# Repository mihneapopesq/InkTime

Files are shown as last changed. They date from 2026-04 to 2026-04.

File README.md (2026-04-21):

# InkTime

## Block Diagram
The system architecture centers on the nRF52840 SoC for wireless connectivity, with power stabilized at 3.3V via an RT6160 buck-boost regulator. It integrates a LiPo battery with USB-C charging alongside an e-paper display, IMU, fuel gauge, and haptic feedback.

Block_Diagram

## Bill of Materials (BOM)

|Component|JLC Part #|Package|Description|Datasheet|
| :--- | :--- | :--- | :--- | :--- |
|SJ1|N/A|Solder Jumper (Copper feature - leave open)|SMD solder JUMPER|N/A|
|R2, R3, R4|[C3920633](https://www.lcsc.com/product-detail/C3920633.html)|0201|7.68k 0201 Thin Film Surface Mount Fixed Resistor +/-0.5% 0.031W CPF0201D7K68C1|[datasheet](https://wmsc.lcsc.com/wmsc/upload/file/pdf/v2/lcsc/2404081048_TE-Connectivity-CPF0201B511RE1_C3920633.pdf)|
|C23, C27, C34, C42|[C21012218](https://www.lcsc.com/product-detail/C21012218.html)|-|Check availability|[datasheet](https://jlc-prod-smt.oss-eu-central-1.aliyuncs.com/smtDataManualFile/8603520985945550848-C21012218.pdf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)|
|EPD_C5|[C9900156064](https://www.lcsc.com/product-detail/C9900156064.html)|201|Generic chip capacitor|[datasheet](https://ds.yuden.co.jp/TYCOMPAS/or/download?pn=MLAST063SCG681JFNA01&fileType=CA)|
|R1_EP_DR|[C3920633](https://www.lcsc.com/product-detail/C3920633.html)|0201|7.68k 0201 Thin Film Surface Mount Fixed Resistor +/-0.5% 0.031W CPF0201D7K68C1|[datasheet](https://wmsc.lcsc.com/wmsc/upload/file/pdf/v2/lcsc/2404081048_TE-Connectivity-CPF0201B511RE1_C3920633.pdf)|
|C15|[C9900156064](https://www.lcsc.com/product-detail/C9900156064.html)|201|Generic chip capacitor|[datasheet](https://ds.yuden.co.jp/TYCOMPAS/or/download?pn=MLAST063SCG681JFNA01&fileType=CA)|
|C5, C7, C8, C12, C19|[C9900156064](https://www.lcsc.com/product-detail/C9900156064.html)|201|Generic chip capacitor|[datasheet](https://ds.yuden.co.jp/TYCOMPAS/or/download?pn=MLAST063SCG681JFNA01&fileType=CA)|
|C11|[C9900156064](https://www.lcsc.com/product-detail/C9900156064.html)|201|Generic chip capacitor|[datasheet](https://ds.yuden.co.jp/TYCOMPAS/or/download?pn=MLAST063SCG681JFNA01&fileType=CA)|
|R2_EP_DR, R9, R_PWR_EPD|[C3920633](https://www.lcsc.com/product-detail/C3920633.html)|0201|7.68k 0201 Thin Film Surface Mount Fixed Resistor +/-0.5% 0.031W CPF0201D7K68C1|[datasheet](https://wmsc.lcsc.com/wmsc/upload/file/pdf/v2/lcsc/2404081048_TE-Connectivity-CPF0201B511RE1_C3920633.pdf)|
|R5, R7, R8|[C3920633](https://www.lcsc.com/product-detail/C3920633.html)|0201|7.68k 0201 Thin Film Surface Mount Fixed Resistor +/-0.5% 0.031W CPF0201D7K68C1|[datasheet](https://wmsc.lcsc.com/wmsc/upload/file/pdf/v2/lcsc/2404081048_TE-Connectivity-CPF0201B511RE1_C3920633.pdf)|
|C1-EP-DR|[C9900156064](https://www.lcsc.com/product-detail/C9900156064.html)|201|Generic chip capacitor|[datasheet](https://ds.yuden.co.jp/TYCOMPAS/or/download?pn=MLAST063SCG681JFNA01&fileType=CA)|
|C24, C39|[C9900179830](https://www.lcsc.com/product-detail/C9900179830.html)|402|0402 (1005 Metric)|N/A|
|L2|[C12669](https://www.lcsc.com/product-detail/C12669.html)|402|Generic chip inductor|[datasheet](https://www.lcsc.com/datasheet/lcsc_datasheet_2304140030_Murata-Electronics-LQG15HS27NJ02D_C12669.pdf)|
|C1, C2, C17, C18|[C9900156064](https://www.lcsc.com/product-detail/C9900156064.html)|201|Generic chip capacitor|[datasheet](https://ds.yuden.co.jp/TYCOMPAS/or/download?pn=MLAST063SCG681JFNA01&fileType=CA)|
|L3|[C12669](https://www.lcsc.com/product-detail/C12669.html)|402|Generic chip inductor|[datasheet](https://www.lcsc.com/datasheet/lcsc_datasheet_2304140030_Murata-Electronics-LQG15HS27NJ02D_C12669.pdf)|
|C3, C4|[C9900156064](https://www.lcsc.com/product-detail/C9900156064.html)|201|Generic chip capacitor|[datasheet](https://ds.yuden.co.jp/TYCOMPAS/or/download?pn=MLAST063SCG681JFNA01&fileType=CA)|
|C29, C30, C31, C32, C37, C38|[C3920633](https://www.lcsc.com/product-detail/C3920633.html)|0201|7.68k 0201 Thin Film Surface Mount Fixed Resistor +/-0.5% 0.031W CPF0201D7K68C1|[datasheet](https://wmsc.lcsc.com/wmsc/upload/file/pdf/v2/lcsc/2404081048_TE-Connectivity-CPF0201B511RE1_C3920633.pdf)|
|EPD_C1, EPD_C2, EPD_C6, EPD_C7, EPD_C8, EPD_C9, EPD_C10, EPD_C11, EPD_C12|[C9900156064](https://www.lcsc.com/product-detail/C9900156064.html)|201|Generic chip capacitor|[datasheet](https://ds.yuden.co.jp/TYCOMPAS/or/download?pn=MLAST063SCG681JFNA01&fileType=CA)|
|R_TYPE_SEL|[C3920633](https://www.lcsc.com/product-detail/C3920633.html)|0201|7.68k 0201 Thin Film Surface Mount Fixed Resistor +/-0.5% 0.031W CPF0201D7K68C1|[datasheet](https://wmsc.lcsc.com/wmsc/upload/file/pdf/v2/lcsc/2404081048_TE-Connectivity-CPF0201B511RE1_C3920633.pdf)|
|SW_DN, SW_ENT, SW_UP|[C569760](https://www.lcsc.com/product-detail/C569760.html)|SMD,3.9x2.9mm|-40℃~+85℃ 1.6N 1.6mm 15V 2.9mm 20mA 3.9mm 500,000 Cycles IP67 J-Lead Rectangular Button SPST Surface Mount,Vertical White With Bracket SMD,3.9x2.9mm Tactile Switches ROHS|[datasheet](https://wmsc.lcsc.com/wmsc/upload/file/pdf/v2/lcsc/2301111010_PANASONIC-EVPAKE31A_C569760.pdf)|
|Q1|[C2564](https://www.lcsc.com/product-detail/C2564.html)|TO-220AB|-55℃~+175℃ 1 P-Channel 180nC@10V 200W 20mΩ@10V 3.4nF 4V 55V 640pF 74A P-Channel TO-220AB MOSFETs ROHS|[datasheet](https://www.lcsc.com/datasheet/lcsc_datasheet_1809041724_Infineon-Technologies-IRF4905PBF_C2564.pdf)|
|C25, C33|[C9900179830](https://www.lcsc.com/product-detail/C9900179830.html)|402|0402 (1005 Metric)|N/A|
|ANT1|[C2917717](https://www.lcsc.com/product-detail/C2917717.html)|1206|-45℃~+125℃ 0.5dBi 1.3mm 1.6mm 100MHz 2.45GHz 2W 3.2mm 50Ω Patch Antenna 1206 Antennas ROHS|[datasheet](https://www.lcsc.com/datasheet/lcsc_datasheet_2404021210_Johanson-Dielectrics-2450AT18B100E_C2917717.pdf)|
|L1|[C12669](https://www.lcsc.com/product-detail/C12669.html)|402|Generic chip inductor|[datasheet](https://www.lcsc.com/datasheet/lcsc_datasheet_2304140030_Murata-Electronics-LQG15HS27NJ02D_C12669.pdf)|
|X2|[C32346](https://www.lcsc.com/product-detail/C32346.html)|SMD3215-2P|-40℃~+85℃ 12.5pF 32.768kHz 70kΩ Crystal Oscillator ±20ppm SMD3215-2P Crystals ROHS|[datasheet](https://www.lcsc.com/datasheet/lcsc_datasheet_2404180925_Seiko-Epson-Q13FC13500004_C32346.pdf)|
|X1|[C9009](https://www.lcsc.com/product-detail/C9009.html)|SMD3225-4P|-40℃~+85℃ 12pF 32MHz Crystal Oscillator ±10ppm ±20ppm SMD3225-4P Crystals ROHS|[datasheet](https://www.lcsc.com/datasheet/lcsc_datasheet_2403291504_YXC-Crystal-Oscillators-X322532MOB4SI_C9009.pdf)|
|R17, R18|[C3920633](https://www.lcsc.com/product-detail/C3920633.html)|0201|7.68k 0201 Thin Film Surface Mount Fixed Resistor +/-0.5% 0.031W CPF0201D7K68C1|[datasheet](https://wmsc.lcsc.com/wmsc/upload/file/pdf/v2/lcsc/2404081048_TE-Connectivity-CPF0201B511RE1_C3920633.pdf)|
|C43|[C9900156064](https://www.lcsc.com/product-detail/C9900156064.html)|201|Generic chip capacitor|[datasheet](https://ds.yuden.co.jp/TYCOMPAS/or/download?pn=MLAST063SCG681JFNA01&fileType=CA)|
|C2-EP-DR|[C9900156064](https://www.lcsc.com/product-detail/C9900156064.html)|201|Generic chip capacitor|[datasheet](https://ds.yuden.co.jp/TYCOMPAS/or/download?pn=MLAST063SCG681JFNA01&fileType=CA)|
|C6, C14, C20, C21|[C9900156064](https://www.lcsc.com/product-detail/C9900156064.html)|201|Generic chip capacitor|[datasheet](https://ds.yuden.co.jp/TYCOMPAS/or/download?pn=MLAST063SCG681JFNA01&fileType=CA)|
|C16|[C9900156064](https://www.lcsc.com/product-detail/C9900156064.html)|201|Generic chip capacitor|[datasheet](https://ds.yuden.co.jp/TYCOMPAS/or/download?pn=MLAST063SCG681JFNA01&fileType=CA)|
|J1|[C122434](https://www.lcsc.com/product-detail/C122434.html)|SMD,P=0.5mm,Surface Mount，Right Angle|FFC & FPC Connectors 0.5mm FPC RA SMT Dual Contact 24Ckt|[datasheet](https://www.molex.com/content/dam/molex/molex-dot-com/products/automated/en-us/salesdrawingpdf/503/503480/5034802400_sd.pdf)|
|R1_USB, R2_USB|[C3920633](https://www.lcsc.com/product-detail/C3920633.html)|0201|7.68k 0201 Thin Film Surface Mount Fixed Resistor +/-0.5% 0.031W CPF0201D7K68C1|[datasheet](https://wmsc.lcsc.com/wmsc/upload/file/pdf/v2/lcsc/2404081048_TE-Connectivity-CPF0201B511RE1_C3920633.pdf)|
|L5|[C1329646](https://www.lcsc.com/product-detail/C1329646.html)|SMD,4.8x4.8mm|1.6A 1.6A 4.7uH 41.4mΩ AEC-Q200 ±30% SMD,4.8x4.8mm Power Inductors ROHS|[datasheet](https://wmsc.lcsc.com/wmsc/upload/file/pdf/v2/lcsc/2304140030_BOURNS-SRR4828A-4R7Y_C1329646.pdf)|
|C9|[C9900156064](https://www.lcsc.com/product-detail/C9900156064.html)|201|Generic chip capacitor|[datasheet](https://ds.yuden.co.jp/TYCOMPAS/or/download?pn=MLAST063SCG681JFNA01&fileType=CA)|
|IC3|[C189517](https://www.lcsc.com/product-detail/C189517.html)|LGA-12(2x2)|Accelerometers Triaxial low-g 12bit Acceleration Sensor|[datasheet](https://www.lcsc.com/datasheet/C189517.pdf)|
|IC1|[C3682423](https://www.lcsc.com/product-detail/C3682423.html)|DSBGA-8(1.1x1.6)|Charger IC Lithium Ion/Polymer, Lithium Iron Phosphate 8-DSBGA (1.6x1.1)|[datasheet](https://www.ti.com/cn/lit/ds/symlink/bq25180.pdf?ts=1775594237116)|
|IC2|[C81079](https://www.lcsc.com/product-detail/C81079.html)|DSBGA-9|Haptic Driver for ERM/LRA with Built-In Library and Smart Loop Architecture|[datasheet](https://www.ti.com/cn/lit/gpn/drv2605)|
|L7|[C5832368](https://www.lcsc.com/product-detail/C5832368.html)|1008|13mΩ 470nH 6.5A 7.5A ±20% 1008 Power Inductors ROHS|[datasheet](https://wmsc.lcsc.com/wmsc/upload/file/pdf/v2/lcsc/2306021632_cjiang--Changjiang-Microelectronics-Tech-FTC252012SR47MBCA_C5832368.pdf)|
|TP (Test Pads)|N/A|N/A|Test pad|N/A|
|J4|[C709357](https://www.lcsc.com/product-detail/C709357.html)|SMD|-40℃~+85℃ 1 10,000 cycles 16P 30V 3A 7.81mm Female Surface Mount, Right Angle Type-C SMD USB Connectors ROHS|[datasheet](https://www.lcsc.com/datasheet/lcsc_datasheet_2404191039_Shenzhen-Kinghelm-Elec-KH-TYPE-C-16P_C709357.pdf)|
|U2|[C2682616](https://www.lcsc.com/product-detail/C2682616.html)|DFN-8-EP(2x2)|-40℃~+85℃ 1 2.5V~4.5V 3uA I2C Lithium Battery DFN-8-EP(2x2) Battery Management ROHS|[datasheet](https://www.lcsc.com/datasheet/lcsc_datasheet_2410121738_Analog-Devices-Inc--Maxim-Integrated-MAX17048G-T10_C2682616.pdf)|
|D2, D4, D5|[C82046](https://www.lcsc.com/product-detail/C82046.html)|SOD-123|ON SEMICONDUCTOR - MBR0530 - DIODE, SCHOTTKY, 0.5A, 30V, SOD-123|[datasheet](https://www.lcsc.com/datasheet/lcsc_datasheet_2304140030_onsemi-MBR0530T1G_C82046.pdf)|
|C10, C13, C22|[C9900156064](https://www.lcsc.com/product-detail/C9900156064.html)|201|Generic chip capacitor|[datasheet](https://ds.yuden.co.jp/TYCOMPAS/or/download?pn=MLAST063SCG681JFNA01&fileType=CA)|
|U1|[C3606653](https://www.lcsc.com/product-detail/C3606653.html)|QFN-48(6x6)|nRF52840|[datasheet](https://www.lcsc.com/datasheet/C3606653.pdf)|
|IC9|[C7065276](https://www.lcsc.com/product-detail/C7065276.html)|WLCSP-15B(2.3x1.4)|Buck-Boost Regulator Positive Output Step-Up/Step-Down I2C DC-DC Controller IC 15-WL-CSP (BSC) (1.4x2.3)|[datasheet](https://wmsc.lcsc.com/wmsc/upload/file/pdf/v2/lcsc/2312271436_Richtek-Tech-RT6160AWSC_C7065276.pdf)|
|Q3|[C469327](https://www.lcsc.com/product-detail/C469327.html)|SOT-323|MOSFET N-Ch 30V 1.5A TrenchFET SC70 Vishay Si1308EDL-T1-GE3 N-channel MOSFET Transistor, 1.5 A, 30 V, 3-Pin SC-70|[datasheet](https://www.lcsc.com/datasheet/lcsc_datasheet_1912202016_Vishay-Intertech-SI1308EDL-T1-GE3_C469327.pdf)|
|J2|[C90533](https://www.lcsc.com/product-detail/C90533.html)|P=1mm|CABLE ADAPTER 6 POS|[datasheet](https://wmsc.lcsc.com/wmsc/upload/file/pdf/v2/lcsc/1810141506_LX-FFC6P1-0mm7CM_C90533.pdf)|
|D3|[C2969755](https://www.lcsc.com/product-detail/C2969755.html)|SOT-23-6L|Low Cap. ESD Protection Auto SOT-23-6 STMicroelectronics USBLC6-2SC6Y, Dual Uni-Directional TVS Diode Array, 6-Pin SOT-23|[datasheet](https://wmsc.lcsc.com/wmsc/upload/file/pdf/v2/lcsc/2211080730_STMicroelectronics-USBLC6-2SC6Y_C2969755.pdf)|

## Hardware Functionality & Technical Architecture

The **InkTime** platform is an ultra-low-power wearable built around the **Nordic nRF52840 SoC**. The design focuses on maximizing battery autonomy through an E-Ink interface and advanced power management, ensuring the device remains functional for weeks on a single charge.

### 1. Core Processing Unit
The **nRF52840 (ARM Cortex-M4F @ 64 MHz)** serves as the system's brain. It was selected for its:
* **Connectivity:** Native Bluetooth 5.4 LE support for smartphone syncing.
* **I/O Versatility:** Integrated USB, SPI, and I2C peripherals to manage all sub-systems.
* **Efficiency:** Advanced "Deep Sleep" modes (sub-10 µA) and a dedicated 32.768 kHz crystal for accurate low-power timing.

### 2. Power & Energy Management
The power tree is designed to extract maximum energy from the **250 mAh Li-Po battery**:
* **Charging:** A **BQ25180 PMIC** manages the CC/CV charging cycle via **USB-C**, providing overvoltage and thermal protection.
* **Regulation:** The **RT6160 Buck-Boost converter** maintains a stable **3.3V** rail even as the battery voltage drops toward 3.0V, outperforming standard LDOs.
* **Fuel Gauge:** The **MAX17048G** monitor provides high-precision State of Charge (SoC) data via I2C, allowing for accurate battery percentage alerts.

### 3. Peripherals and User Interface
* **E-Paper Display (1.54"):** Connected via a 24-pin FPC (SPI). It draws power only during refreshes, making it ideal for static data. A dedicated driving circuit with MOSFETs and Schottky diodes manages the necessary bias voltages.
* **Motion Sensing:** The **BMA423 IMU (I2C)** enables "wrist-tilt" wake-up and step counting, allowing the MCU to stay in sleep mode until motion is detected.
* **Haptic Feedback:** The **DRV2605 driver** handles the vibration motor (shaker), offloading PWM waveform generation from the MCU for crisp, customizable alerts.
* **User Input:** Three physical buttons (`SW_UP`, `SW_ENT`, `SW_DN`) provide a reliable navigation interface.

### 4. Power Profile & Autonomy
With an average current draw ($I_{avg}$) of approximately **180 µA** (combining deep sleep, sensor polling, and periodic display updates), the theoretical autonomy is:

$$T = \frac{250\text{ mAh}}{0.18\text{ mA}} \approx 1389\text{ hours}$$

In real-world scenarios, this translates to an estimated **10–14 days** of continuous operation.

## nRF52840 Signal Assignment & Connectivity

| Pin(s) | Peripheral | Function | Justification |
| :--- | :--- | :--- | :--- |
| **P0.02** | SPI SCK | Clock | SPI clock for the E-Ink display interface. |
| **P0.03** | SPI MOSI | Data | Master Out Slave In; sends pixel data to display. |
| **P0.05** | EPD CS | Chip Select | Active-low signal to enable SPI display communication. |
| **P0.15** | EPD DC | Control | Toggles between Data and Command modes for E-Ink. |
| **P0.16** | EPD RST | Control | Provides a hardware reset path for the display. |
| **P0.17** | EPD BUSY | Status Input | Hardware flag indicating active display refresh cycles. |
| **P0.06** | I2C SDA | Data | Serial Data line shared by IMU, Fuel Gauge, and Haptics. |
| **P0.07** | I2C SCL | Clock | Serial Clock line for the high-speed I2C bus. |
| **P0.08** | IMU INT1 | Interrupt | Primary motion/event trigger from BMA421/BMA423. |
| **P1.08** | IMU INT2 | Interrupt | Secondary interrupt line for advanced motion features. |
| **P0.09** | Fuel Gauge ALERT | Interrupt | Real-time battery status alert from MAX17048. |
| **P0.11** | PMIC INT | Interrupt | Fault or charging status update from BQ25180. |
| **P0.12** | HAPTIC_EN | Control | Master enable signal for the DRV2605 haptic driver. |
| **P0.13** | Button UP | GPIO Input | Digital input for the 'Up' navigation switch. |
| **P0.14** | Button ENTER | GPIO Input | Digital input for the 'Enter/Select' switch. |
| **P1.02** | Button DOWN | GPIO Input | Digital input for the 'Down' navigation switch. |
| **P0.18** | nRESET | Reset | System hardware reset (Reset pin). |
| **D+ / D-** | USB Interface | USB Data | Dedicated lines for USB communication and charging. |
| **SWDIO** | Debug Port | Data | Serial Wire Debug bidirectional data line. |
| **SWDCLK** | Debug Port | Clock | Serial Wire Debug clock reference. |

## Design Log & Validation

### 1. Engineering Decisions
* **Density:** Used **0201 passives** and **1.0 mm PCB thickness** to fit all 49 components on the **TOP layer** within the compact enclosure.
* **RF Performance:** Maintained a strict **copper-free keep-out zone** under the 2.4 GHz antenna and used **via stitching** to stabilize the ground planes.
* **Routing:** Power lines are **0.3 mm** for stability, while data lines are **0.15 mm**. Decoupling caps are placed within **0.5 mm** of IC pins to minimize noise.

### 2. Approved Errors (DRC & ERC)
The following warnings were manually verified and intentionally accepted:

| Error Type | Reason for Approval |
| :--- | :--- |
| **DRC: Dimensions** | Button and USB-C placement is fixed by the **mechanical cutouts** of the 3D-printed case. |
| **DRC: Overlap** | Caused by **via-in-pad / escape routing** (0.15mm vias). Necessary for the dense fanout of the nRF52840. |
| **ERC: Input Pins Only** | Verified manually; all nets are functionally connected despite the CAD warning. |
| **ERC: Power Pins** | Confirmed that all supply rails (3V3, VBAT) are correctly routed to their regulators. |

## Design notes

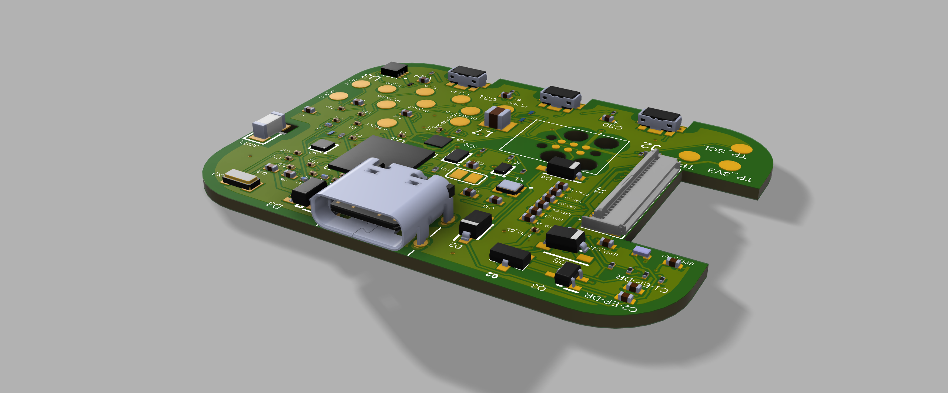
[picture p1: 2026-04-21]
Images/PCB_3D_Side2.png

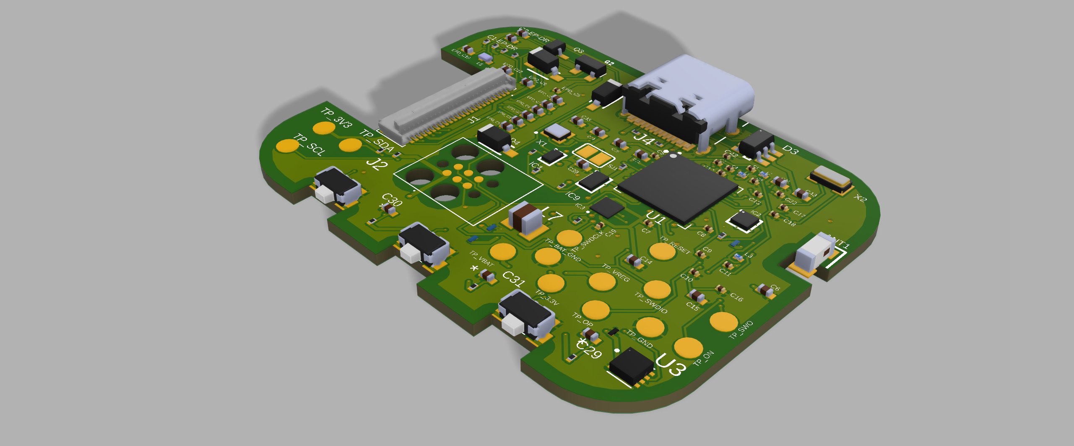
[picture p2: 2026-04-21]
Images/PCB_3D_Side1.png

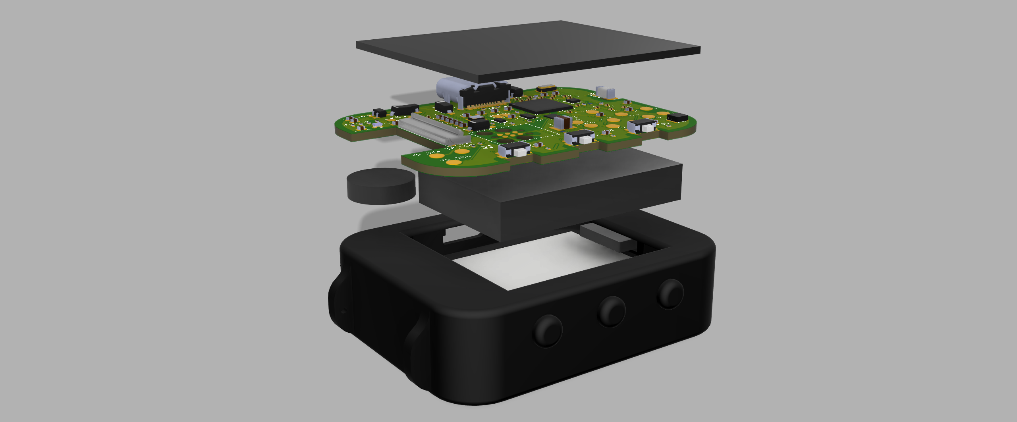
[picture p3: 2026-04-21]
Images/Exploded.png

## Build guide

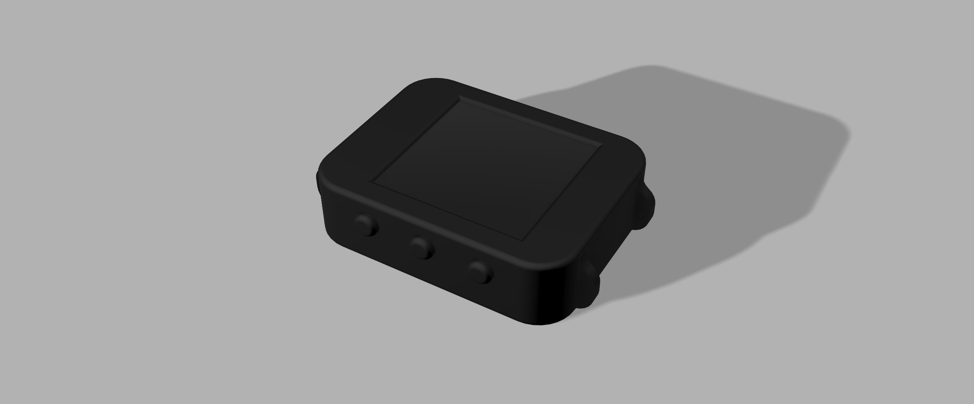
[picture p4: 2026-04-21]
Images/Assembly.png

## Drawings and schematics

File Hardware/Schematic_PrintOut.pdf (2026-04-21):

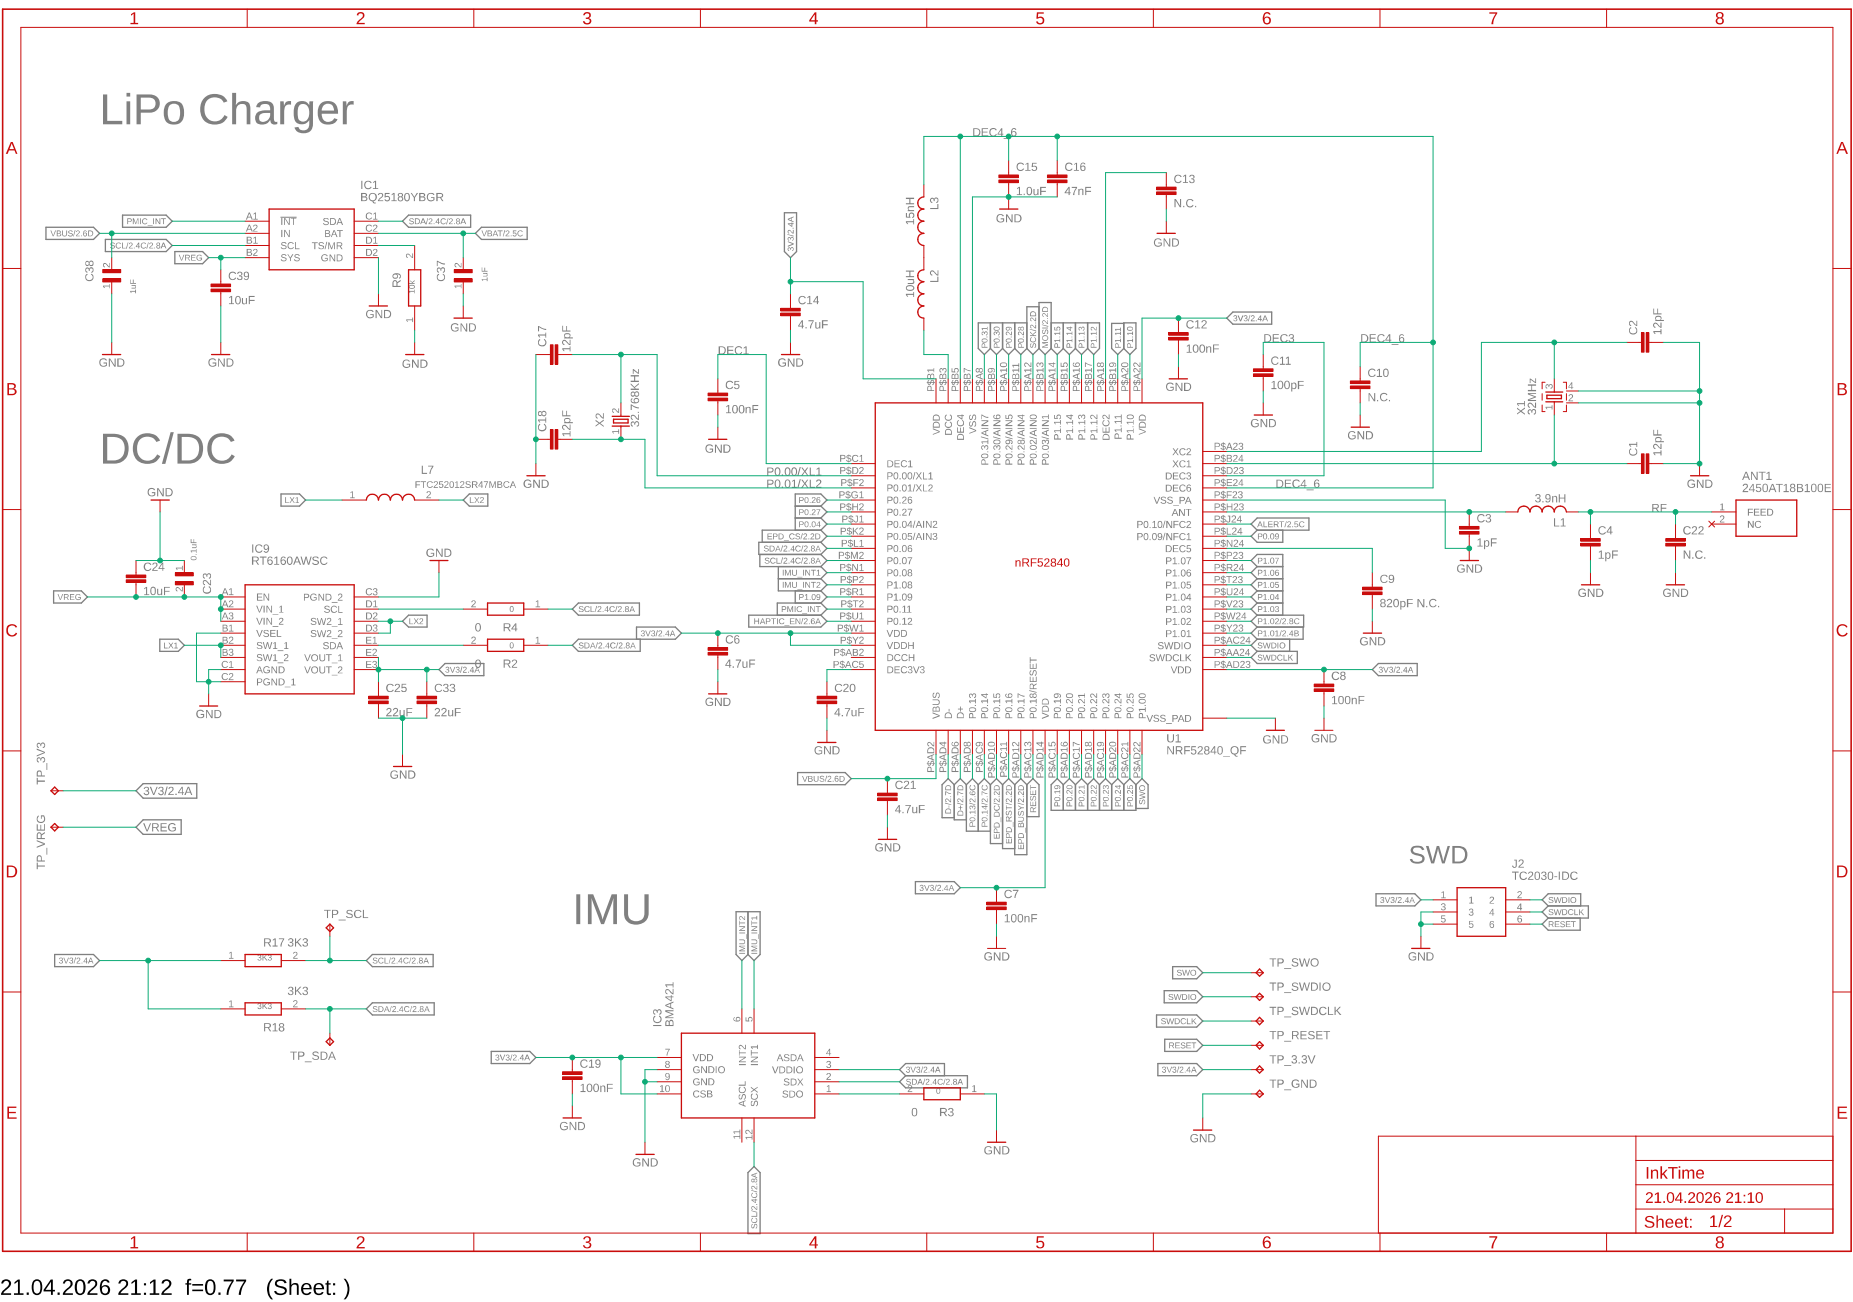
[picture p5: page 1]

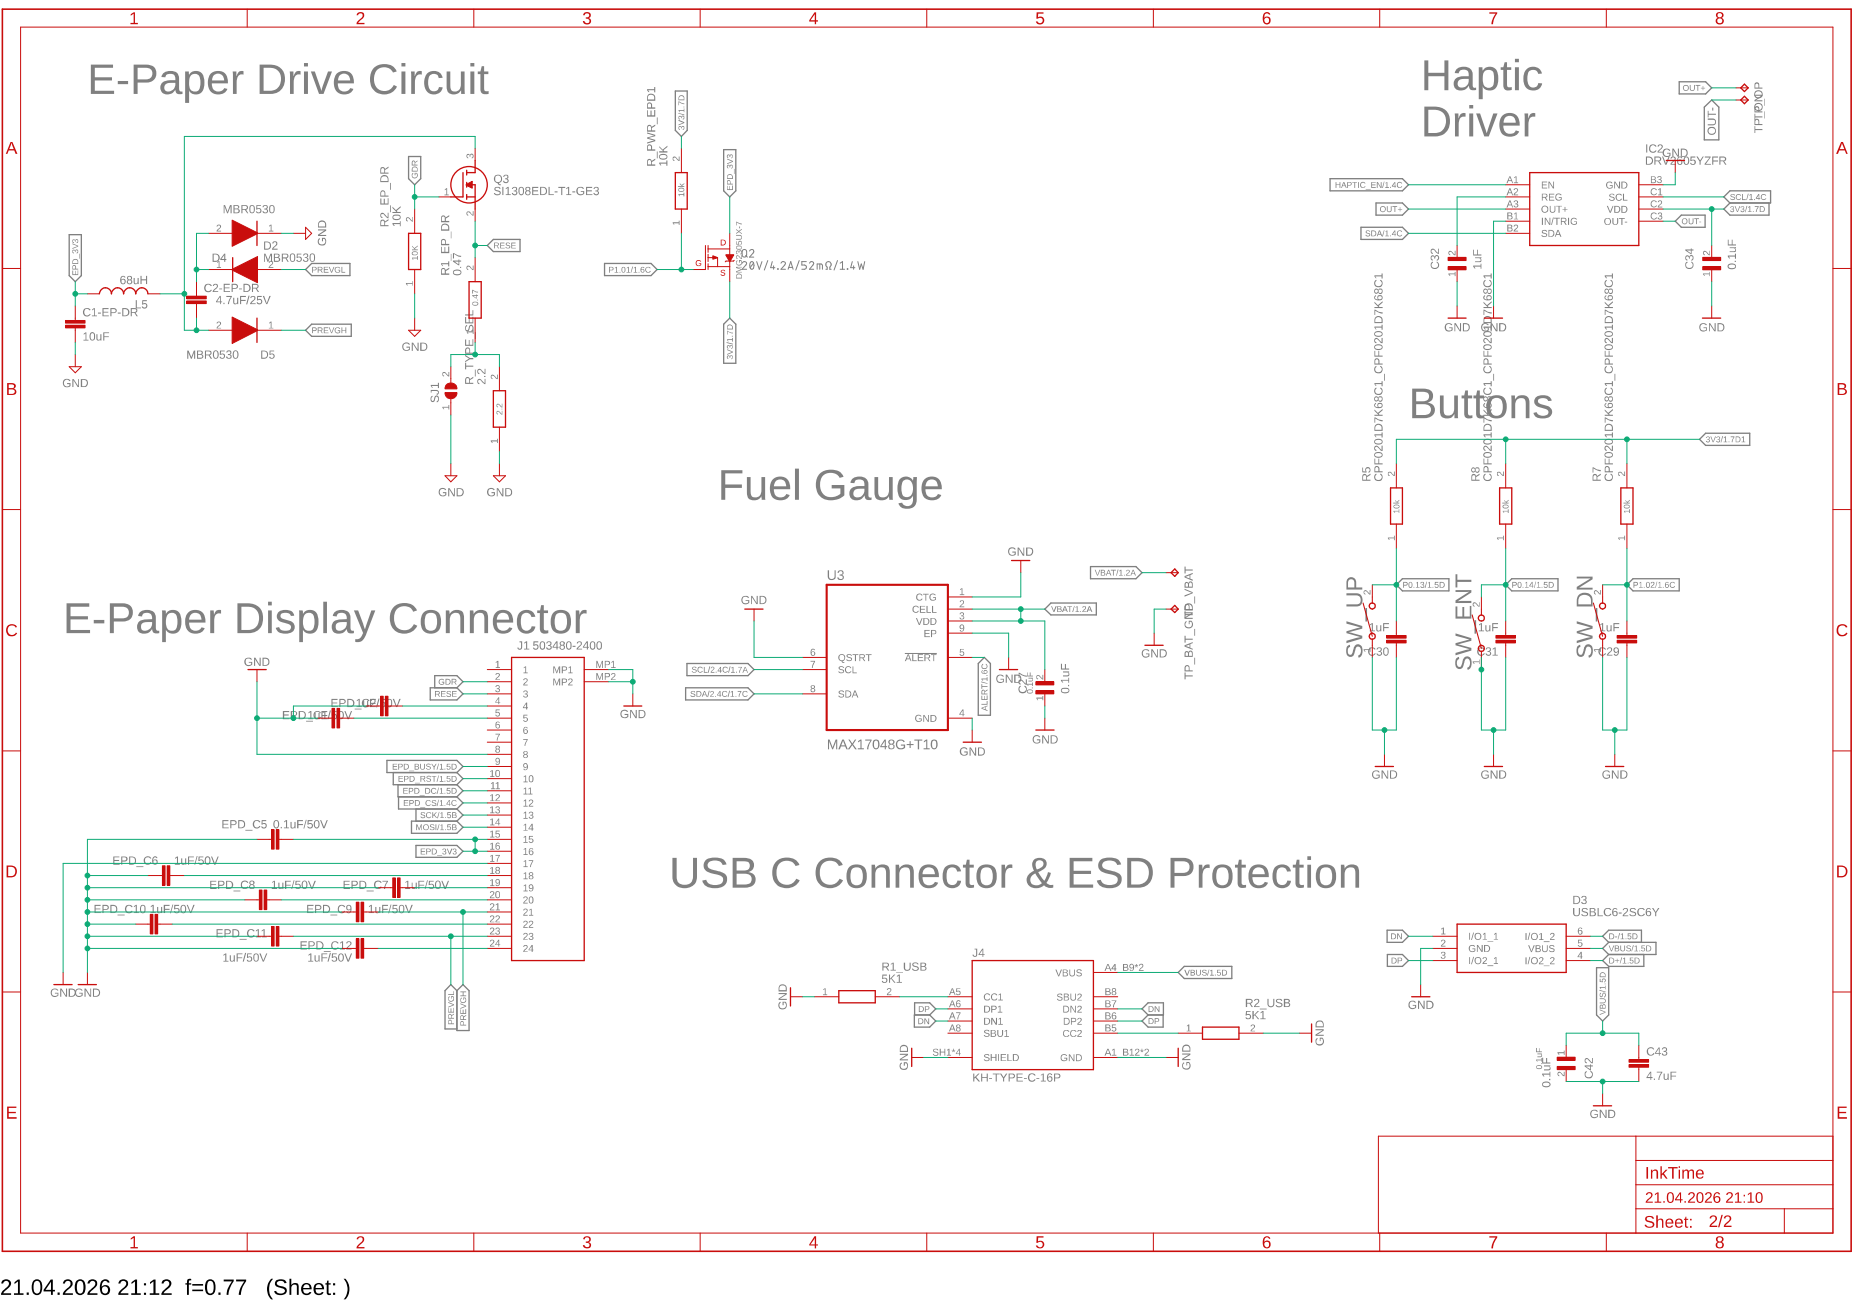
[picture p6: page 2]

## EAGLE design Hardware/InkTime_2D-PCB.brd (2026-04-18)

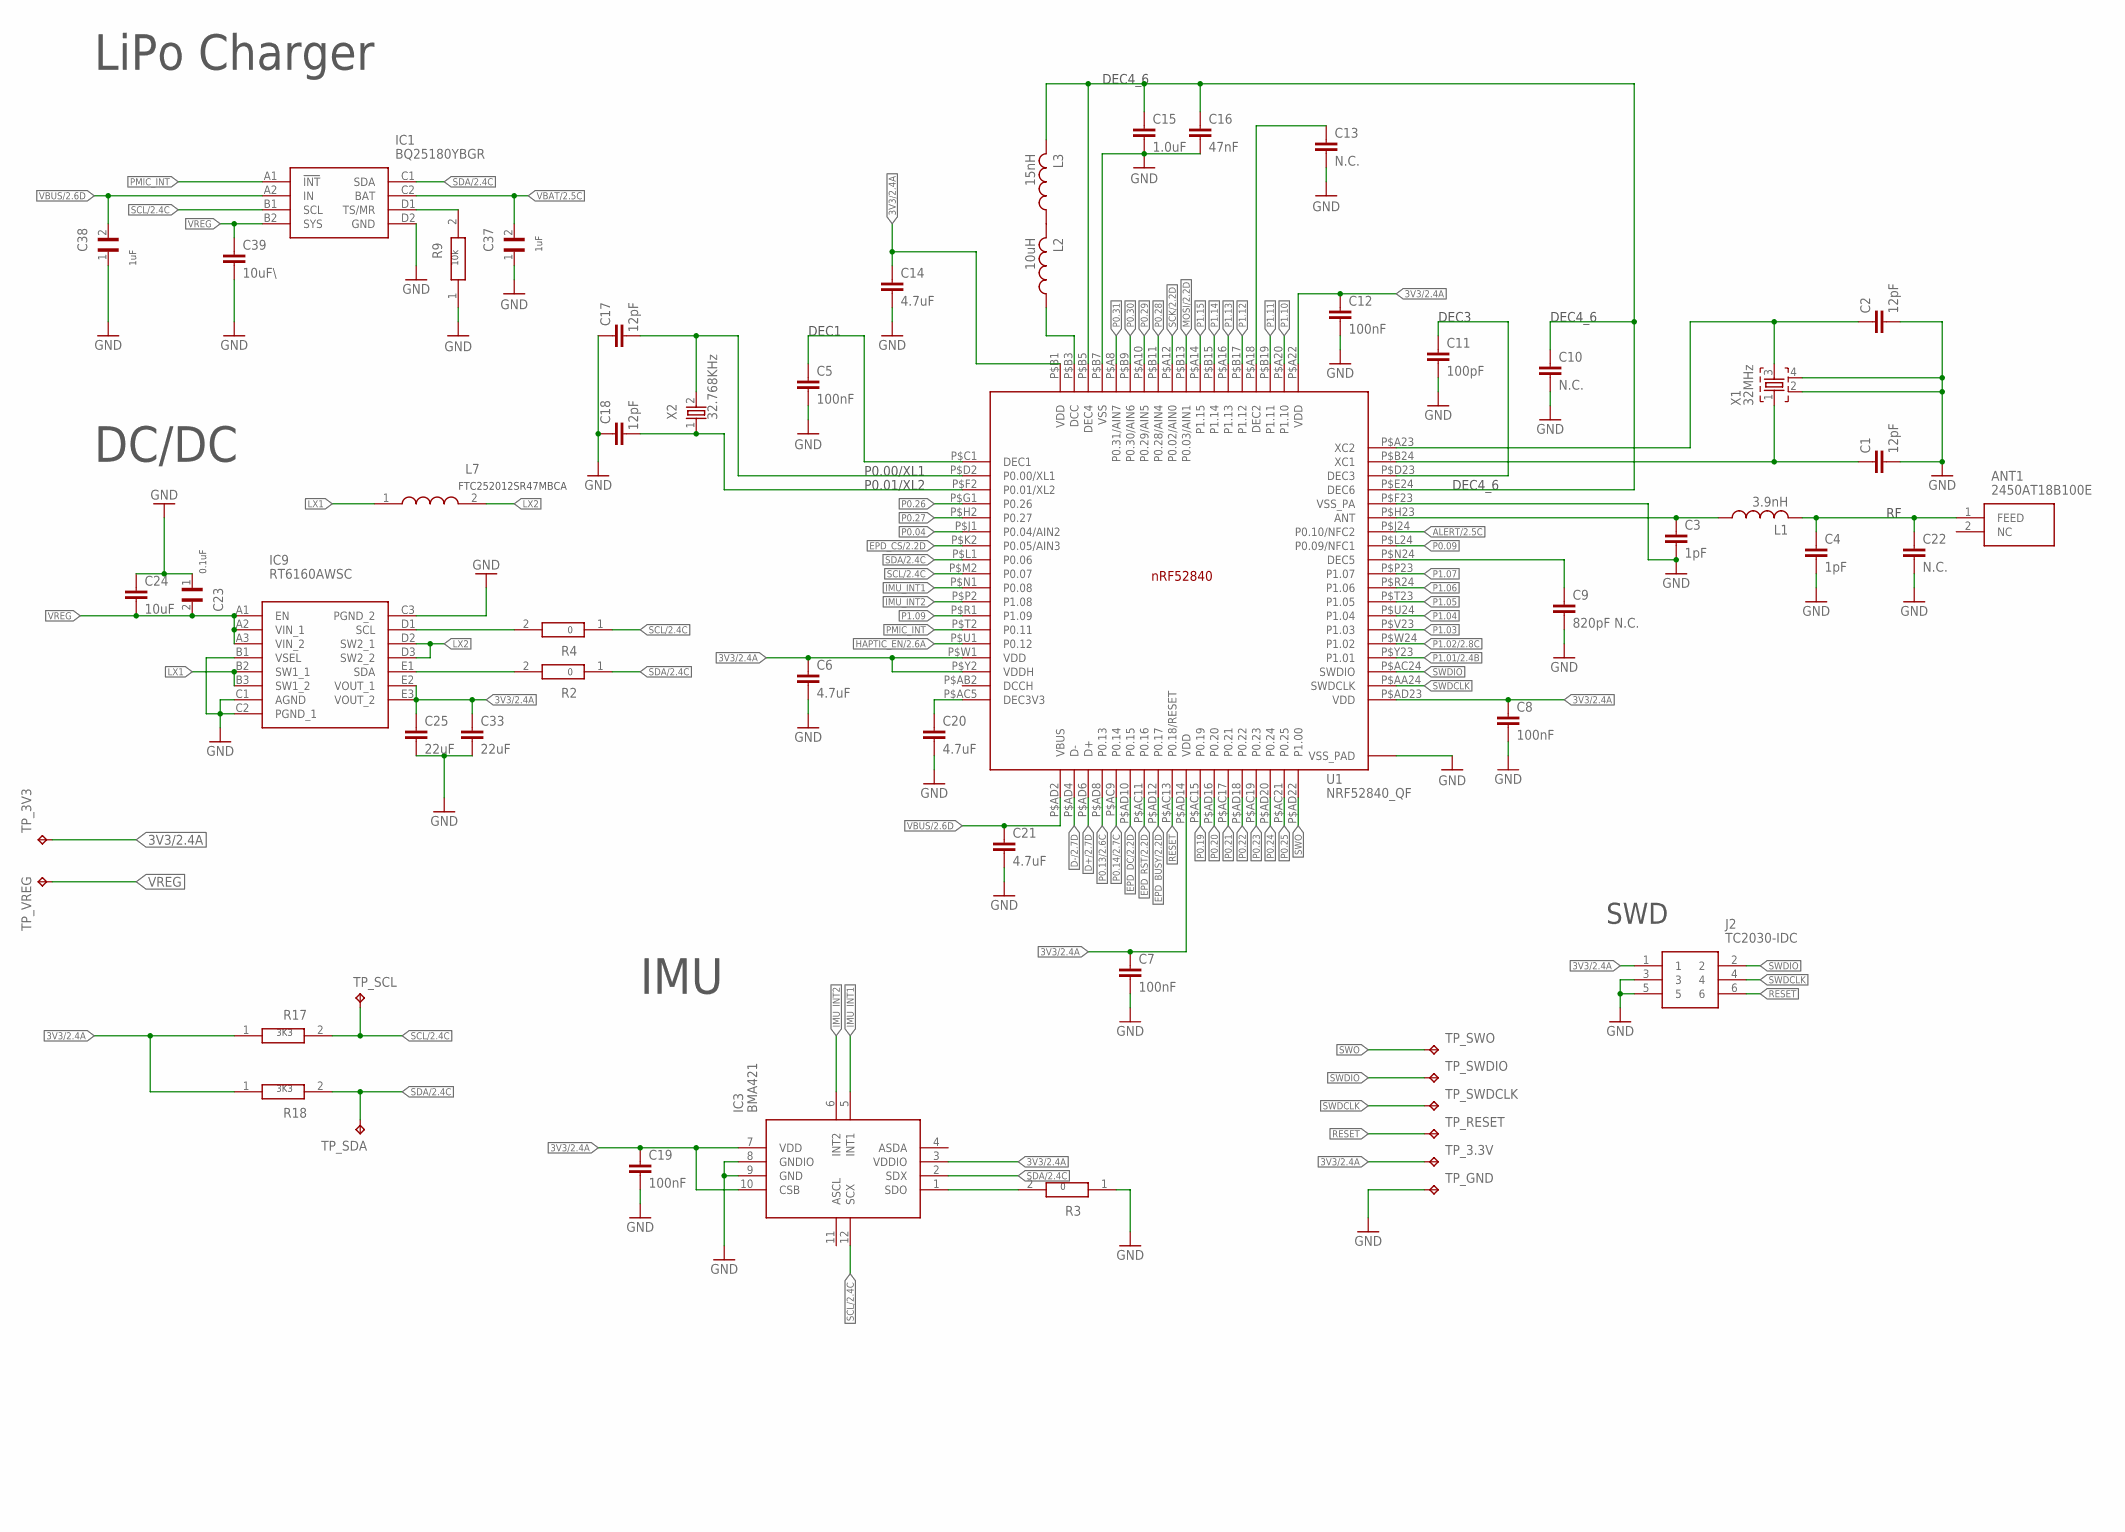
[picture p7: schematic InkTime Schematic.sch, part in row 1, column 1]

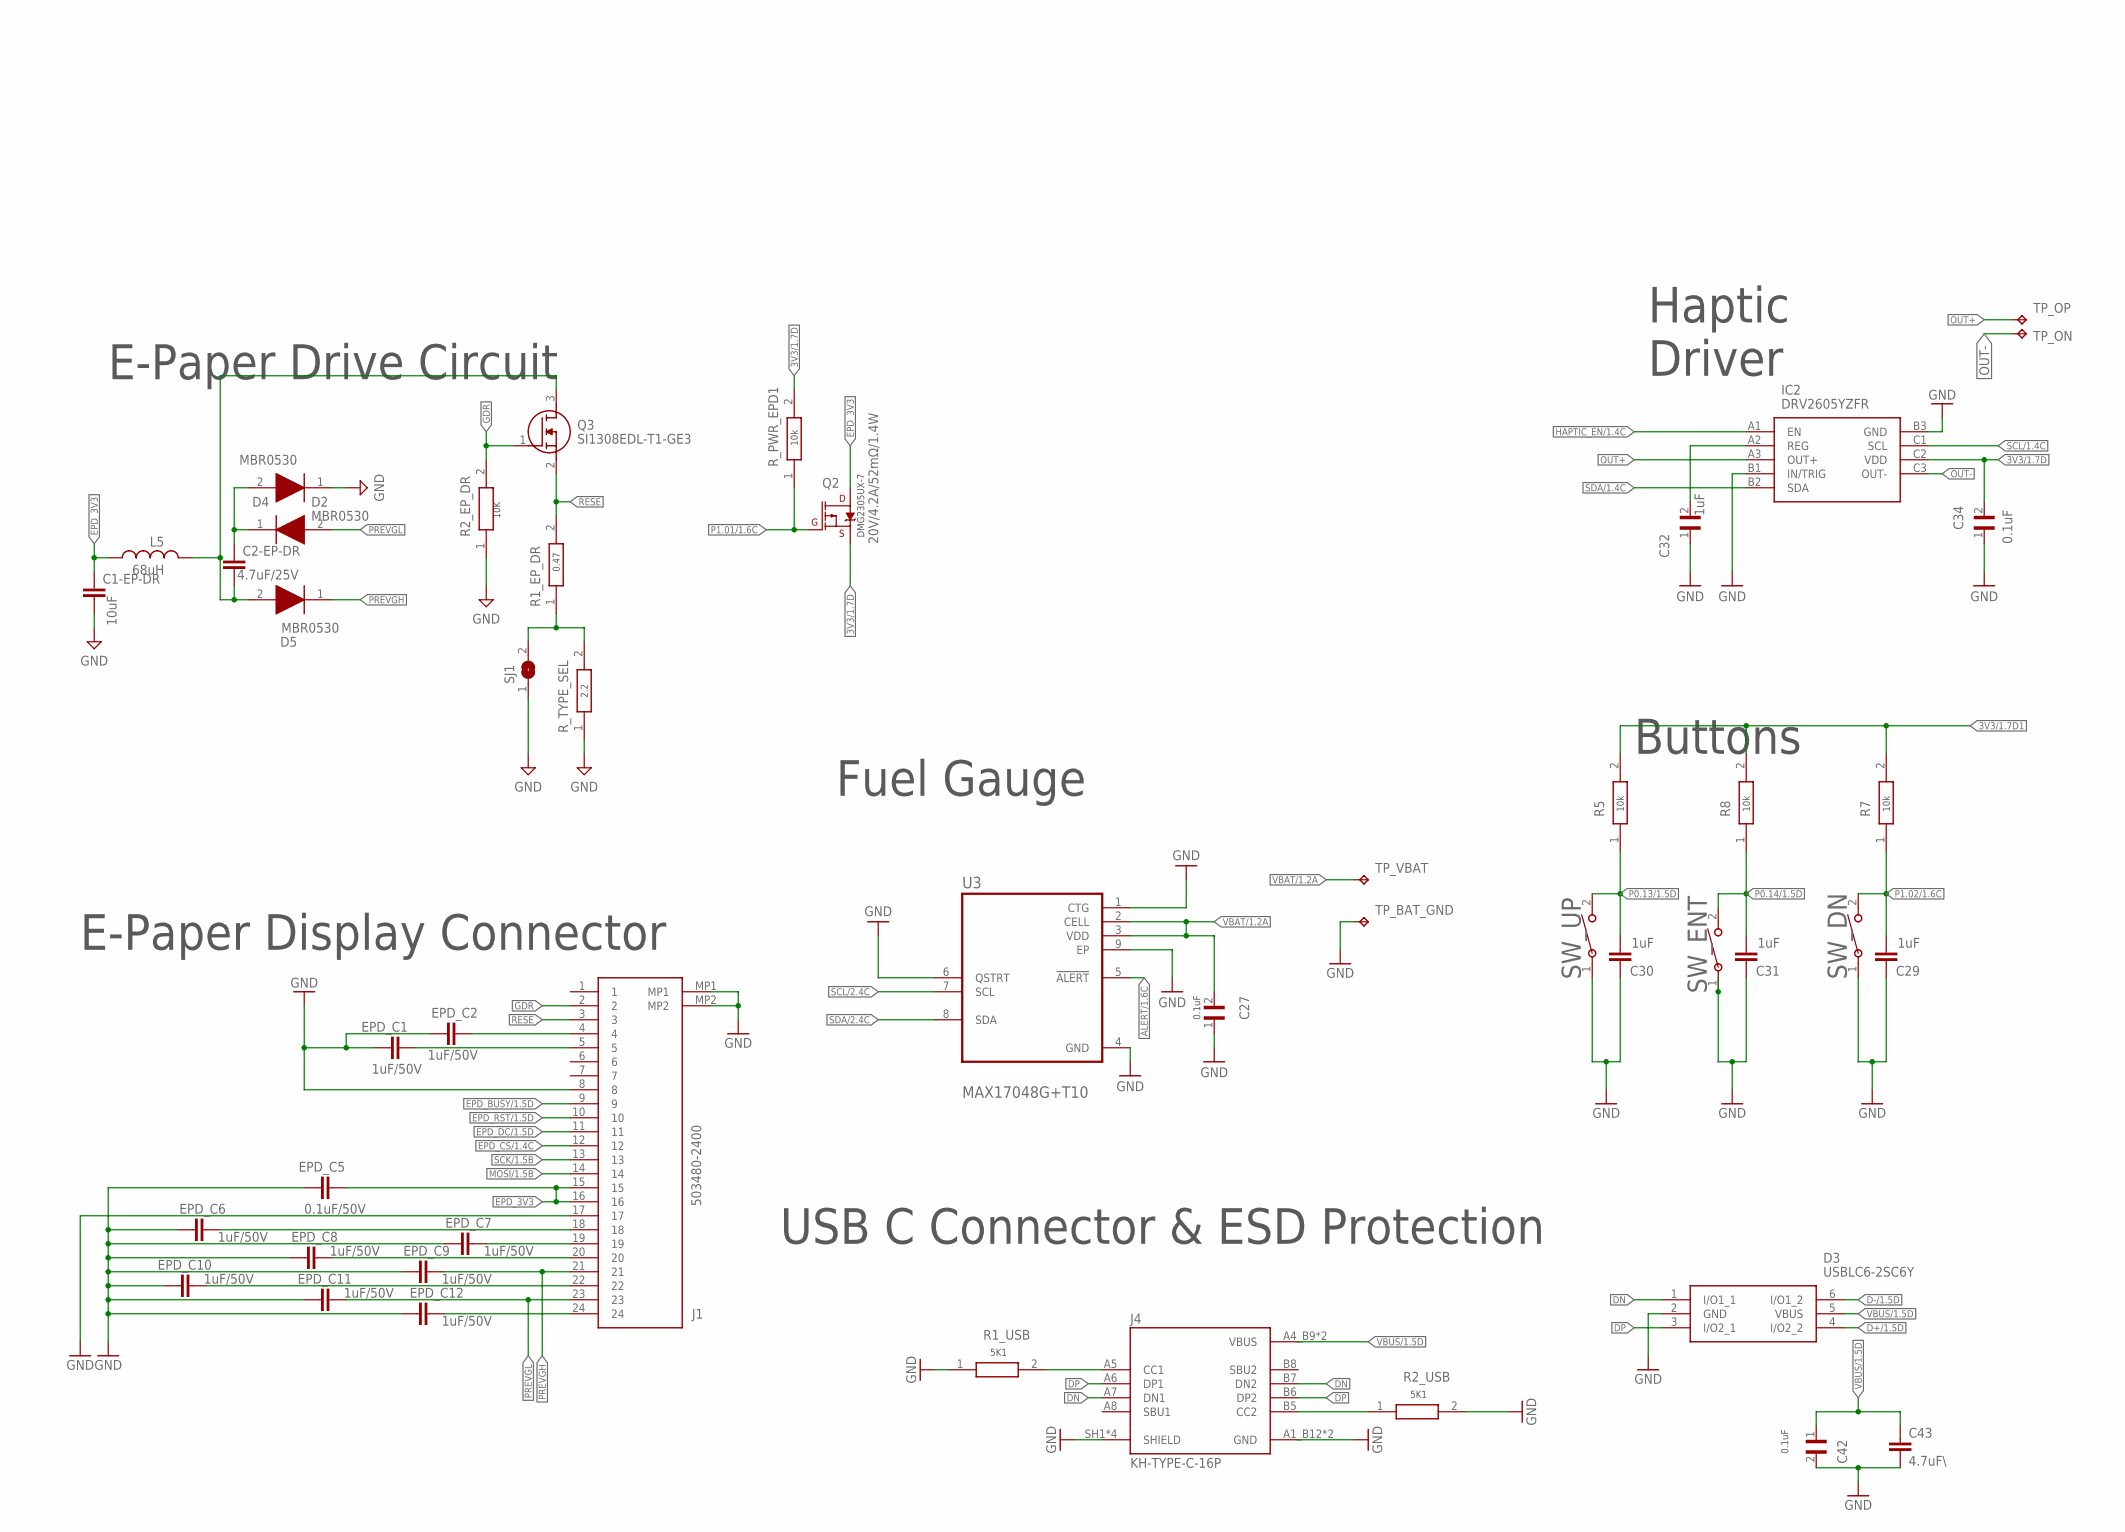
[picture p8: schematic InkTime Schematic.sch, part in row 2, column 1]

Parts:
ANT1: 2450AT18B100E; 2450AT18B100E_ANTC3216X140N
C1, C2, C17, C18: 12pF; NORDIC_NRF_3_RESC0201_L
C1-EP-DR: 10uF; NORDIC_NRF_3_RESC0402_L
C2-EP-DR: 4.7uF/25V; NORDIC_NRF_3_RESC0402_L
C3, C4: 1pF; NORDIC_NRF_3_RESC0201_L
C5, C7, C8, C12, C19: 100nF; NORDIC_NRF_3_RESC0201_L
C6, C14, C20, C21: 4.7uF; NORDIC_NRF_3_RESC0402_L
C9: 820pF N.C.; NORDIC_NRF_3_RESC0201_L
C10, C13, C22: N.C.; NORDIC_NRF_3_RESC0201_L
C11: 100pF; NORDIC_NRF_3_RESC0201_L
C15: 1.0uF; NORDIC_NRF_3_RESC0402_L
C16: 47nF; NORDIC_NRF_3_RESC0201_L
C23, C27, C34: 0.1uF; GRM011R60J152KE01L_1_0201
C24: 10uF; PERFECT_0402_0402
C25, C33: 22uF; NORDIC_NRF_3_RESC0402_L
C29, C30, C31: 1uF; NORDIC_NRF_3_RESC0402_L
C32, C37, C38: 1uF; GRM011R60J152KE01L_1_0201
C39: 10uF\; NORDIC_NRF_3_RESC0402_L
C42: 0.1uF; GRM011R60J152KE01L_2_CAPC0201X13N
C43: 4.7uF\; NORDIC_NRF_3_RESC0402_L
D2, D4, D5: MBR0530; ESP32_C6_LIBRARY_5_SOD3716X135N
D3: USBLC6-2SC6Y; ESP32_C6_LIBRARY_3_SOT95P280X145-6N
EPD_C1, EPD_C2, EPD_C6, EPD_C7, EPD_C8, EPD_C9, EPD_C10, EPD_C11, EPD_C12: 1uF/50V; NORDIC_NRF_3_RESC0402_L
EPD_C5: 0.1uF/50V; NORDIC_NRF_3_RESC0201_L
IC1: BQ25180YBGR; BQ25180YBGR_BGA8C40P2X4_100X155X50
IC2: DRV2605YZFR; DRV2605YZFR_BGA9C50P3X3_144X144X62
IC3: BMA421; BMA423_BMA423
IC9: RT6160AWSC; RT6160AWSC_BGA15C40P3X5_140X230X60
J1: 503480-2400; 503480-2400_5034802400
J2: TC2030-IDC; TC2030-IDC_TC2030IDC
J4: KH-TYPE-C-16P; KH-TYPE-C-16P_KINGHELM_KH-TYPE-C-16P
L1: 3.9nH; NORDIC_NRF_2_RESC0201_L
L2: 10uH; NORDIC_NRF_2_RESC0201_L
L3: 15nH; NORDIC_NRF_2_RESC0201_L
L5: 68uH; NORDIC_NRF_2_RESC0402_L
L7: FTC252012SR47MBCA; MLP2016SR47MT0S1_INDC2016X100N
Q2: 20V/4.2A/52mΩ/1.4W; ESP32_C6_LIBRARY_4_ESP32_C6_LIBRARY_4_ESP32_C6_LIBRARY_4_ES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
Q3: SI1308EDL-T1-GE3; ESP32_C6_LIBRARY_6_SOT65P210X110-3N
R1_EP_DR: 0.47; CPF0201D7K68C1_0201
R1_USB, R2_USB: 5K1; CPF0201D7K68C1_0201
R2, R3, R4: 0; CPF0201D7K68C1_0201
R2_EP_DR: 10K; CPF0201D7K68C1_0201
R5, R7, R8: CPF0201D7K68C1_CPF0201D7K68C1; CPF0201D7K68C1_0201
R9: 10K; ERA-1AEB3401C_0201
R17, R18: 3K3; CPF0201D7K68C1_0201
R_PWR_EPD1: 10K; CPF0201D7K68C1_0201
R_TYPE_SEL: 2.2; CPF0201D7K68C1_0201
SJ1: ESP32_C6_LIBRARY_7_JUMPER_SJ
SW_DN: 2025-10-22_07-23-44_LIBRARY_EVP-AKE31ASW_EVP-AKE3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; 2025-10-22_07-23-44_LIBRARY_SW_EVP-AKE31A_PAN
SW_ENT: 2025-10-22_07-23-44_LIBRARY_EVP-AKE31ASW_EVP-AKE3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; 2025-10-22_07-23-44_LIBRARY_SW_EVP-AKE31A_PAN
SW_UP: 2025-10-22_07-23-44_LIBRARY_EVP-AKE31ASW_EVP-AKE3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; 2025-10-22_07-23-44_LIBRARY_SW_EVP-AKE31A_PAN
TP_3.3V, TP_3V3: HECTOR_WATCH_1_TPTP20R; HECTOR_WATCH_1_TP20R
TP_BAT_GND: HECTOR_WATCH_1_TPTP20R; HECTOR_WATCH_1_TP20R
TP_GND: HECTOR_WATCH_1_TPTP20R; HECTOR_WATCH_1_TP20R
TP_ON: HECTOR_WATCH_1_TPTP20R; HECTOR_WATCH_1_TP20R
TP_OP: HECTOR_WATCH_1_TPTP20R; HECTOR_WATCH_1_TP20R
TP_RESET: HECTOR_WATCH_1_TPTP20R; HECTOR_WATCH_1_TP20R
TP_SCL: HECTOR_WATCH_1_TPTP20R; HECTOR_WATCH_1_TP20R
TP_SDA: HECTOR_WATCH_1_TPTP20R; HECTOR_WATCH_1_TP20R
TP_SWDCLK: HECTOR_WATCH_1_TPTP20R; HECTOR_WATCH_1_TP20R
TP_SWDIO: HECTOR_WATCH_1_TPTP20R; HECTOR_WATCH_1_TP20R
TP_SWO: HECTOR_WATCH_1_TPTP20R; HECTOR_WATCH_1_TP20R
TP_VBAT: HECTOR_WATCH_1_TPTP20R; HECTOR_WATCH_1_TP20R
TP_VREG: HECTOR_WATCH_1_TPTP20R; HECTOR_WATCH_1_TP20R
U1: NRF52840_QF; NORDIC_NRF_4_AQFN50P700X700X85_HS-74N
U3: MAX17048G+T10; ESP32_C6_LIBRARY_SON50P200X200X80-9N
X1: 32MHz; NORDIC_NRF_BT-XTAL_2016_N
X2: 32.768KHz; NORDIC_NRF_1_XTAL_3215_N

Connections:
3V3/1.7D: C34.2, IC2.C2 (VDD), Q2.2 (S), R_PWR_EPD1.2
3V3/1.7D1: R5.2, R7.2, R8.2
3V3/2.4A: C6.1, C7.1, C8.1, C12.1, C14.1, C19.1, C25.1, C33.1, IC3.3 (VDDIO), IC3.7 (VDD), IC3.10 (CSB), IC9.E2 (VOUT_1), IC9.E3 (VOUT_2), J2.1, R17.1, R18.1, TP_3.3V.TP, TP_3V3.TP, U1.P$A22 (VDD), U1.P$AD14 (VDD), U1.P$AD23 (VDD), U1.P$B1 (VDD), U1.P$W1 (VDD), U1.P$Y2 (VDDH)
ALERT/1.6C: U3.5 (!ALERT)
ALERT/2.5C: U1.P$J24 (P0.10/NFC2)
D+/1.5D: D3.4 (I/O2_2)
D+/2.7D: U1.P$AD6 (D+)
D-/1.5D: D3.6 (I/O1_2)
D-/2.7D: U1.P$AD4 (D-)
DN: D3.1 (I/O1_1), J4.A7 (DN1), J4.B7 (DN2)
DP: D3.3 (I/O2_1), J4.A6 (DP1), J4.B6 (DP2)
EPD_3V3: C1-EP-DR.1, EPD_C5.2, J1.15, J1.16, L5.1, Q2.3 (D)
EPD_BUSY/1.5D: J1.9
EPD_BUSY/2.2D: U1.P$AD12 (P0.17)
EPD_CS/1.4C: J1.12
EPD_CS/2.2D: U1.P$K2 (P0.05/AIN3)
EPD_DC/1.5D: J1.11
EPD_DC/2.2D: U1.P$AD10 (P0.15)
EPD_RST/1.5D: J1.10
EPD_RST/2.2D: U1.P$AC11 (P0.16)
GDR: J1.2, Q3.1 (G), R2_EP_DR.2
GND: C1.2, C1-EP-DR.2, C2.2, C3.2, C4.2, C5.2, C6.2, C7.2, C8.2, C9.2, C10.2, C11.2, C12.2, C13.2, C14.2, C15.2, C16.2, C17.2, C18.2, C19.2, C20.2, C21.2, C22.2, C23.1, C24.1, C25.2, C27.1, C29.1, C30.1, C31.1, C32.1, C33.2, C34.1, C37.1, C38.1, C39.2, C42.2, C43.2, D3.2 (GND), D4.1 (K), EPD_C1.1, EPD_C2.1, EPD_C5.1, EPD_C6.1, EPD_C7.1, EPD_C8.1, EPD_C9.1, EPD_C10.1, EPD_C11.1, EPD_C12.1, IC1.D2 (GND), IC2.B1 (IN/TRIG), IC2.B3 (GND), IC3.8 (GNDIO), IC3.9 (GND), IC9.B1 (VSEL), IC9.C1 (AGND), IC9.C2 (PGND_1), IC9.C3 (PGND_2), J1.8, J1.17, J1.MP1, J1.MP2, J2.3, J2.5, J4.A1_B12 (GND), J4.A12_B1 (GND), J4.SH1 (SHIELD), J4.SH2 (SHIELD), J4.SH3 (SHIELD), J4.SH4 (SHIELD), R1_USB.1, R2_EP_DR.1, R2_USB.2, R3.1, R9.1, SJ1.1, SW_DN.1, SW_ENT.1, SW_UP.1, TP_BAT_GND.TP, TP_GND.TP, U1.P$74 (VSS_PAD), U1.P$75 (VSS_PAD), U1.P$76 (VSS_PAD), U1.P$77 (VSS_PAD), U1.P$78 (VSS_PAD), U1.P$79 (VSS_PAD), U1.P$80 (VSS_PAD), U1.P$81 (VSS_PAD), U1.P$82 (VSS_PAD), U1.P$83 (VSS_PAD), U1.P$84 (VSS_PAD), U1.P$85 (VSS_PAD), U1.P$86 (VSS_PAD), U1.P$87 (VSS_PAD), U1.P$88 (VSS_PAD), U1.P$89 (VSS_PAD), U1.P$90 (VSS_PAD), U1.P$B7 (VSS), U1.P$F23 (VSS_PA), U3.1 (CTG), U3.4 (GND), U3.6 (QSTRT), U3.9 (EP), X1.2, X1.4
HAPTIC_EN/1.4C: IC2.A1 (EN)
HAPTIC_EN/2.6A: U1.P$U1 (P0.12)
IMU_INT1: IC3.5 (INT1), U1.P$N1 (P0.08)
IMU_INT2: IC3.6 (INT2), U1.P$P2 (P1.08)
LX1: IC9.B2 (SW1_1), IC9.B3 (SW1_2), L7.1
LX2: IC9.D2 (SW2_1), IC9.D3 (SW2_2), L7.2
MOSI/1.5B: J1.14
MOSI/2.2D: U1.P$B13 (P0.03/AIN1)
unnamed: C13.1, U1.P$A18 (DEC2)
unnamed: C20.1, U1.P$AC5 (DEC3V3)
unnamed: C9.1, U1.P$N24 (DEC5)
unnamed: L2.1, U1.P$B3 (DCC)
unnamed: L2.2, L3.1
unnamed: C10.1, C15.1, C16.1, L3.2, U1.P$B5 (DEC4), U1.P$E24 (DEC6)
unnamed: C5.1, U1.P$C1 (DEC1)
unnamed: C17.1, U1.P$D2 (P0.00/XL1), X2.2
unnamed: C18.1, U1.P$F2 (P0.01/XL2), X2.1
unnamed: C11.1, U1.P$D23 (DEC3)
unnamed: C2.1, U1.P$A23 (XC2), X1.3
unnamed: C1.1, U1.P$B24 (XC1), X1.1
unnamed: ANT1.1 (FEED), C4.1, C22.1, L1.2
unnamed: C3.1, L1.1, U1.P$H23 (ANT)
unnamed: IC9.D1 (SCL), R4.2
unnamed: IC9.E1 (SDA), R2.2
unnamed: IC1.D1 (TS/MR), R9.2
unnamed: EPD_C2.2, J1.4
unnamed: EPD_C1.2, J1.5
unnamed: EPD_C6.2, J1.18
unnamed: EPD_C7.2, J1.19
unnamed: EPD_C8.2, J1.20
unnamed: IC3.1 (SDO), R3.2
unnamed: EPD_C10.2, J1.22, R_TYPE_SEL.1
unnamed: EPD_C12.2, J1.24
unnamed: C32.2, IC2.A2 (REG)
unnamed: C2-EP-DR.2, D5.2 (A), L5.2, Q3.3 (D)
unnamed: C2-EP-DR.1, D2.1 (K), D4.2 (A)
unnamed: R1_EP_DR.1, R_TYPE_SEL.2, SJ1.2
unnamed: J4.A5 (CC1), R1_USB.2
unnamed: J4.B5 (CC2), R2_USB.1
OUT+: IC2.A3 (OUT+), TP_OP.TP
OUT-: IC2.C3 (OUT-), TP_ON.TP
P0.04: U1.P$J1 (P0.04/AIN2)
P0.09: U1.P$L24 (P0.09/NFC1)
P0.13/1.5D: C30.2, R5.1, SW_UP.2
P0.13/2.6C: U1.P$AD8 (P0.13)
P0.14/1.5D: C31.2, R8.1, SW_ENT.2
P0.14/2.7C: U1.P$AC9 (P0.14)
P0.19: U1.P$AC15 (P0.19)
P0.20: U1.P$AD16 (P0.20)
P0.21: U1.P$AC17 (P0.21)
P0.22: U1.P$AD18 (P0.22)
P0.23: U1.P$AC19 (P0.23)
P0.24: U1.P$AD20 (P0.24)
P0.25: U1.P$AC21 (P0.25)
P0.26: U1.P$G1 (P0.26)
P0.27: U1.P$H2 (P0.27)
P0.28: U1.P$B11 (P0.28/AIN4)
P0.29: U1.P$A10 (P0.29/AIN5)
P0.30: U1.P$B9 (P0.30/AIN6)
P0.31: U1.P$A8 (P0.31/AIN7)
P1.01/1.6C: Q2.1 (G), R_PWR_EPD1.1
P1.01/2.4B: U1.P$Y23 (P1.01)
P1.02/1.6C: C29.2, R7.1, SW_DN.2
P1.02/2.8C: U1.P$W24 (P1.02)
P1.03: U1.P$V23 (P1.03)
P1.04: U1.P$U24 (P1.04)
P1.05: U1.P$T23 (P1.05)
P1.06: U1.P$R24 (P1.06)
P1.07: U1.P$P23 (P1.07)
P1.09: U1.P$R1 (P1.09)
P1.10: U1.P$A20 (P1.10)
P1.11: U1.P$B19 (P1.11)
P1.12: U1.P$B17 (P1.12)
P1.13: U1.P$A16 (P1.13)
P1.14: U1.P$B15 (P1.14)
P1.15: U1.P$A14 (P1.15)
PMIC_INT: IC1.A1 (!INT), U1.P$T2 (P0.11)
PREVGH: D5.1 (K), EPD_C9.2, J1.21
PREVGL: D2.2 (A), EPD_C11.2, J1.23
RESE: J1.3, Q3.2 (S), R1_EP_DR.2
RESET: J2.6, TP_RESET.TP, U1.P$AC13 (P0.18/RESET)
SCK/1.5B: J1.13
SCK/2.2D: U1.P$A12 (P0.02/AIN0)
SCL/1.4C: IC2.C1 (SCL)
SCL/2.4C: IC1.B1 (SCL), IC3.12 (SCX), R4.1, R17.2, TP_SCL.TP, U1.P$M2 (P0.07), U3.7 (SCL)
SDA/1.4C: IC2.B2 (SDA)
SDA/2.4C: IC1.C1 (SDA), IC3.2 (SDX), R2.1, R18.2, TP_SDA.TP, U1.P$L1 (P0.06), U3.8 (SDA)
SWDCLK: J2.4, TP_SWDCLK.TP, U1.P$AA24 (SWDCLK)
SWDIO: J2.2, TP_SWDIO.TP, U1.P$AC24 (SWDIO)
SWO: TP_SWO.TP, U1.P$AD22 (P1.00)
VBAT/1.2A: C27.2, TP_VBAT.TP, U3.2 (CELL), U3.3 (VDD)
VBAT/2.5C: C37.2, IC1.C2 (BAT)
VBUS/1.5D: C42.1, C43.1, D3.5 (VBUS), J4.A4_B9 (VBUS), J4.A9_B4 (VBUS)
VBUS/2.6D: C21.1, C38.2, IC1.A2 (IN), U1.P$AD2 (VBUS)
VREG: C23.2, C24.2, C39.1, IC1.B2 (SYS), IC9.A1 (EN), IC9.A2 (VIN_1), IC9.A3 (VIN_2), TP_VREG.TP

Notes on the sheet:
SWD
DEC1
DEC3
DEC4_6
LiPo Charger
10k
DC/DC
1uF
0.1uF
3K3
IMU
E-Paper Display Connector
Fuel Gauge
E-Paper Drive Circuit
0.47
2.2
10K
USB C Connector & ESD Protection
5K1
DMG2305UX-7
Haptic Driver
Buttons
FTC252012SR47MBCA
P0.00/XL1
P0.01/XL2

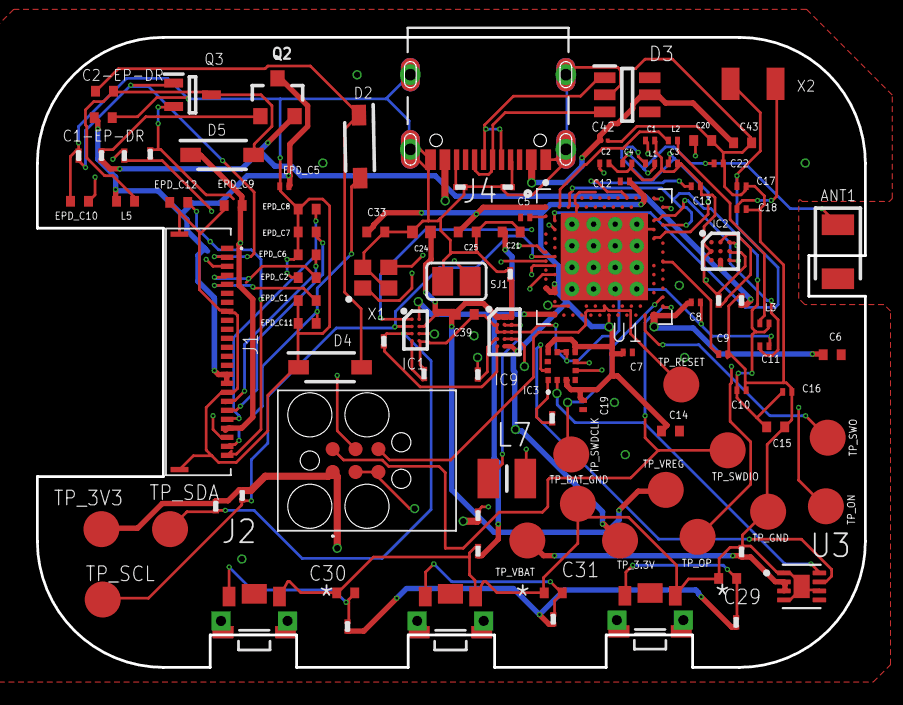
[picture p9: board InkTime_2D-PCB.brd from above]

Board: 4 copper layers, 46.0 x 35.0 mm, 105 parts (0 on the bottom side), 64 nets.

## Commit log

2026-04-15 Fix 90 degree nets Fixes #2
    [InkTime_2D-PCB.brd]
2026-04-15 Add missing reference Fixes #1
    [InkTime Schematic.sch]
2026-04-16 Fix antenna cutout and update X2 component library
    Fixes #4
    Fixes #9
    [InkTime_2D-PCB.brd]
2026-04-17 Fix nets and symbol naming inconsistencies
    Fixes #8
    [InkTime Schematic.sch]
2026-04-17 Completed Ground Plane for the 4-layer routing
    Fixes #3
    [InkTime_2D-PCB.brd]
2026-04-17 Placed decoupling capacitors close to the associated pins
    Fixes #10
    [InkTime_2D-PCB.brd]
2026-04-18 Simplified Silkscreen and optimized routing areas
    Fixes #11 and Fixes #5
    [InkTime_2D-PCB.brd]
2026-04-21 Update Schematic and Upload PrintOut
    [InkTime Schematic.sch]
2026-04-21 Revise README with project name and detailed architecture
    Updated project name from 'InkTIme' to 'InkTime' and added detailed sections on block diagram, bill of materials, hardware functionality, and technical architecture.

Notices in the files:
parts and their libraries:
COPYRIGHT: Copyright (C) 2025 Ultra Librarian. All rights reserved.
